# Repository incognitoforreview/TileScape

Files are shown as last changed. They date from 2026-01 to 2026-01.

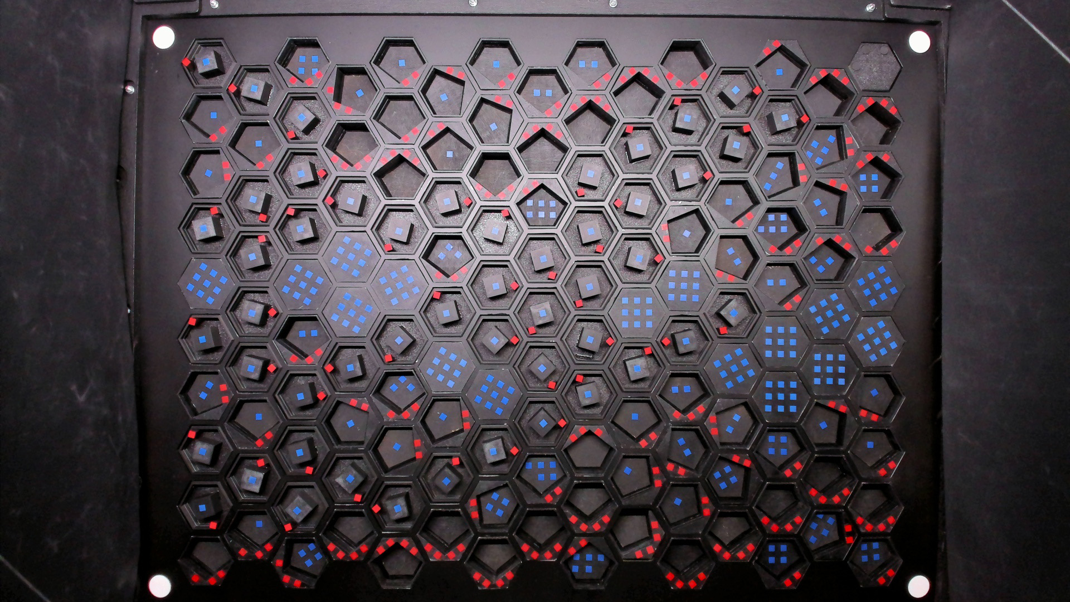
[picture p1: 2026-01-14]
input_files/DMG_table1.jpg

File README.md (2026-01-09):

# TileScape
A repository for the tangible interaction-based TileScape set-up developed for tabletop games, including (1) design files to create the tabletop set-up; (2) template files to create tangible game pieces; and (3) the tracking algorithm to capture the game pieces placed on the tabletop.

## Build & Test
The design_files folder offers shape files, drawings and instructions for building TileScape or create an adapted version. It is set-up with subfolders around certain parts of the set-up, with each folder containing a readme pdf.

The code in the main folder is used to track the physical game pieces on TileScape's board. It can be initiated by creating an object of the TileScape class located in the tilescape.py file. It can be run in a test mode, which takes images from the TileScape set-up located in the input_files folder as a basis. The main call in tilescape.py currently initiates this test mode. To run it, you will need to set a local folder in line 64.

## Use & cite
All files and code are shared under the GPL-3.0 license (see license tab). By downloading and using TileScape, you agree to cite TileScape in any publication based on research in which TileScape is used or that builds on its concept. 

When citing TileScape, the following APA style reference can be used:

[anonimized for peer review] (2026). TileScape: A Stackable Tile Gaming Tabletop for Shaping Discrete 3D Terrains with Augmented Physics Simulations. [Manuscript submitted for publication]. [removed for peer review].

## Contact & Support
If you have questions, want some support or simply get in contact about this work, please contact [removed for peer review] via [removed for peer review].

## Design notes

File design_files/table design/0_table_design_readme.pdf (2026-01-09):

In this folder, subfolders are located with each containing specic information to produce the TIlescape or a similar set-up.

The gure on the right shows the full set-up as presented in the paper [citation anonimized for peer review]. Each folder focuses on a subpart of the set-up with its own les and a dedicated readme for instructions.

Any changes to the set-up (e.g. dierent grid size or use of dierent hardware) may need adaption of the les in this repository.

Please reach out for any guidance where needed or if any instructions are unclear or seem incomplete.

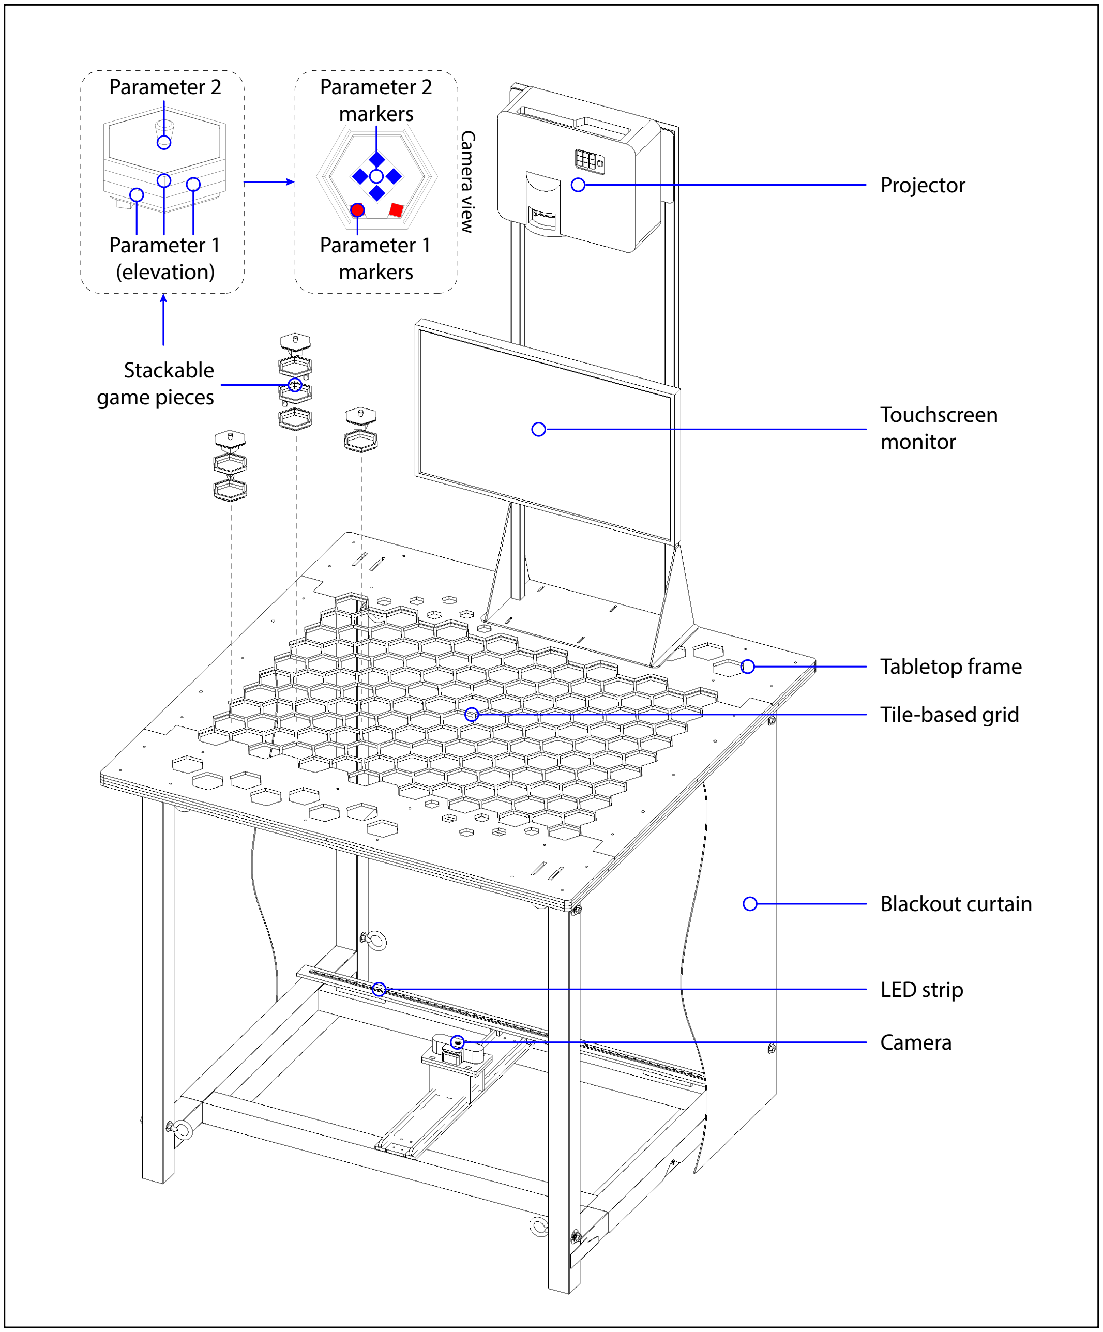
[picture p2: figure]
Projector; Parameter 2; markers; Parameter 1 (elevation); Parameter 1 markers; Camera view; Stackable; game pieces; Touchscreen; monitor; Tabletop frame; Tile-based grid; Blackout curtain; LED strip; Camera

Figure source: [Anonimized for peer review] (2026). TileScape: A Stackable Tile Gaming Tabletop for Shaping Discrete 3D Terrains with Augmented Physics Simulations [Manuscript submitted for publication]. [Anonimized for peer review].

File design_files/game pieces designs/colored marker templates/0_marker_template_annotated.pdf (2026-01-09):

The colored markers are squares, added as stickers in the color used for a specic parameter. We used a sticker printer capable of cutting the squares from a uniform color sticker, using transfer tape to preserve equal spacing betweek markers. The blue boxes indicate patterns for number of markers from 1 to 9.

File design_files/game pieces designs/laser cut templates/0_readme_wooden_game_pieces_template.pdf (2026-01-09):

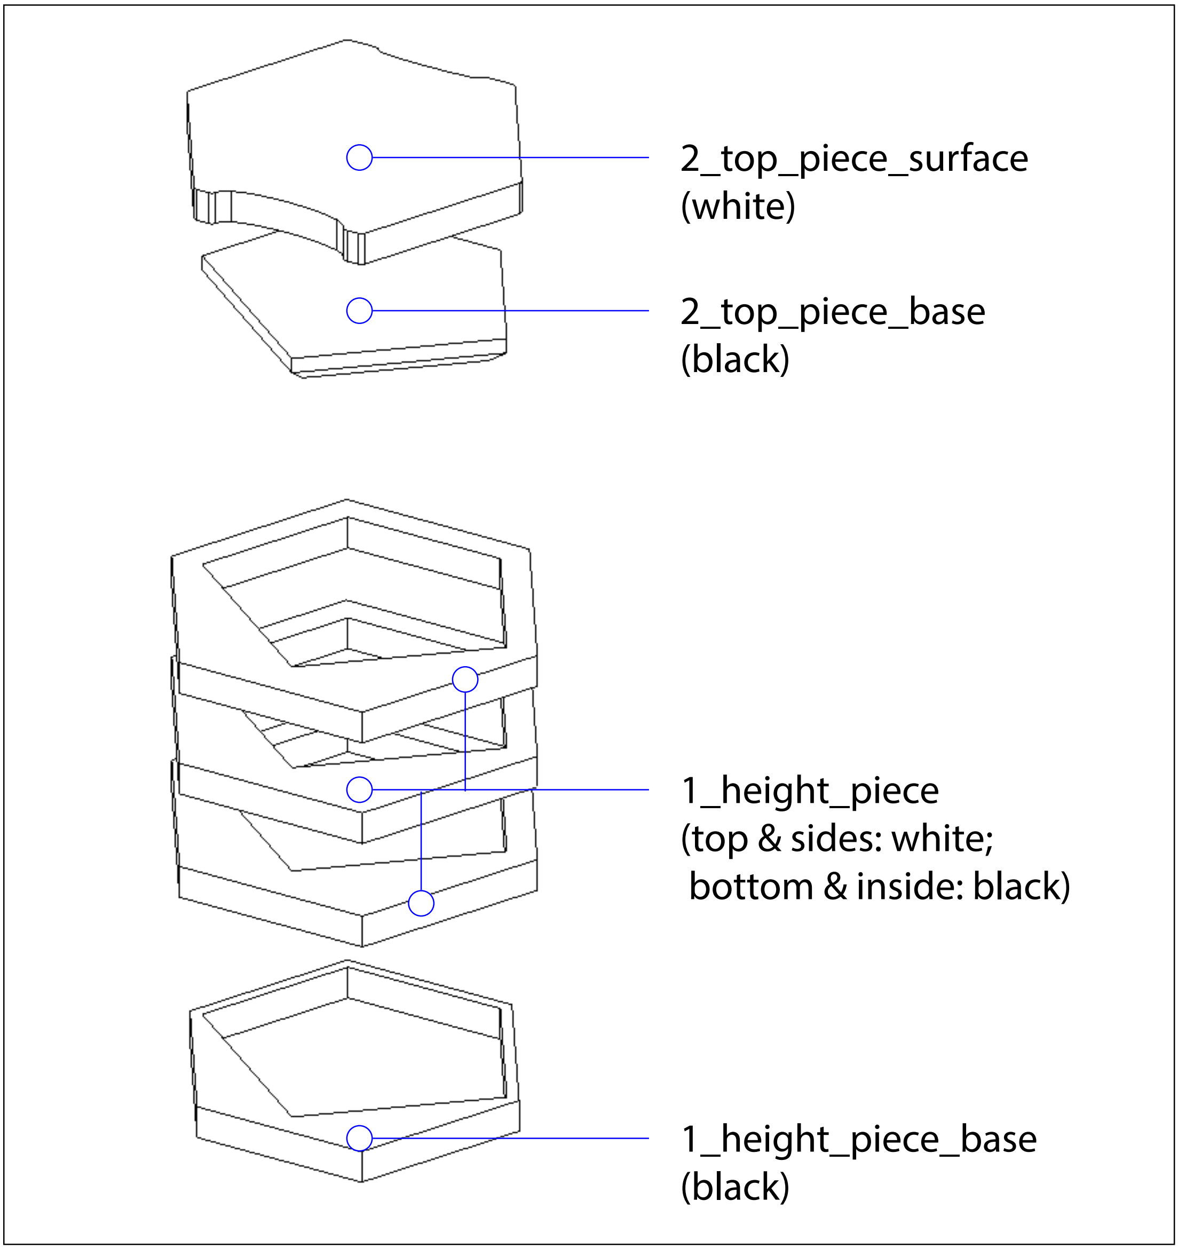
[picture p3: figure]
2_top_piece_surface (white); 2_top_piece_base (black); 1_height_piece (top & sides: white; bottom & inside: black); 1_height_piece_base (black)

The les in this folder oer templates for lasercutting layered pieces from wood for use on Tilescape. Each template is oered as a .dxf and .ai (Adobe Illustrator). All parts can be laser cut from standard wood sheets. We recommend 6 mm thick sheets.

The gure on the right shows the template les and how they are stacked on Tilescape. Dierent number of 1_height_piece can be glued together for dierent levels of elevation. We recommend to use a mold for glueing from the inner shapes cut out for creating the pieces and sanding the resulting shape after glueing. Afterwards, the pieces require painting, with recommended colors shown on the gure per shape. We recommend a matte paint nish. After painting, glue the les for 1 together and do the same for 2, which can then be stacked ontop of each other.

The 2_top_piece_surface can be modied to include 2D icons or 3D shapes to represent meanings. 3D shapes can be freely designed and glued ontop. We recommend creating 2D icons by including cut-out shapes in the lasercutting, which then shows the surface of the black 2_top_piece_base underneath to create a contrast. Using stickers is an alternative, but may add reections to the top-down projections.

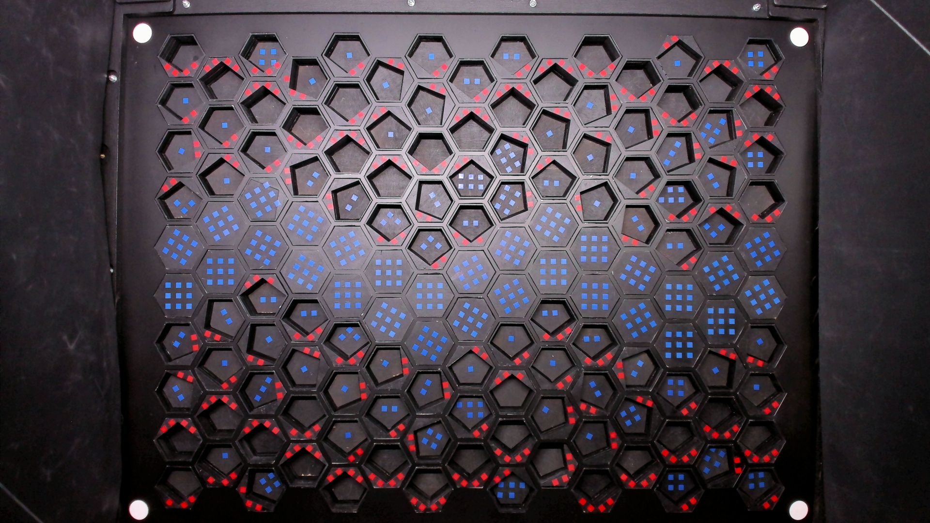
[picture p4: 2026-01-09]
input_files/VRG_table1.jpg

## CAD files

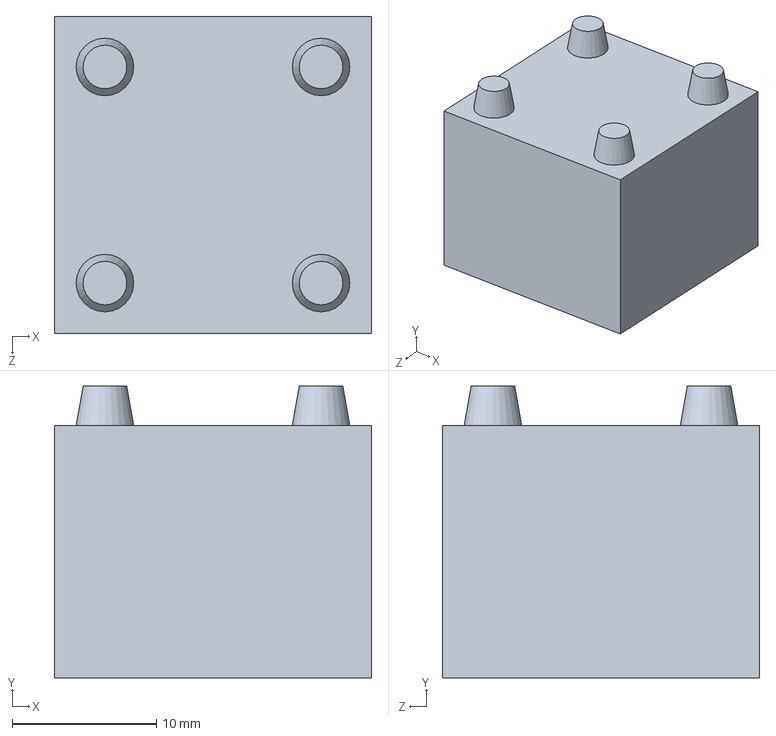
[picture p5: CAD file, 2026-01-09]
design_files/game pieces designs/3D print templates/3_top_piece_extension_template.SLDPRT
22.0 x 20.2 x 22.0 mm

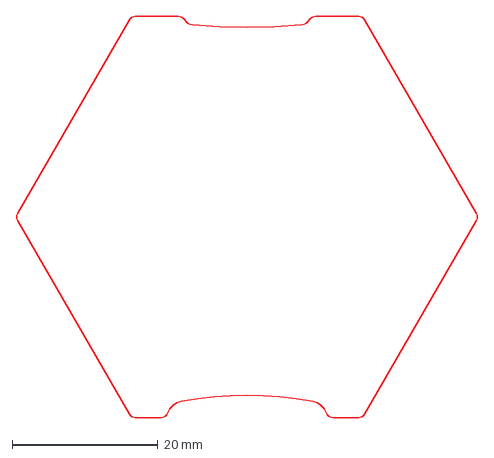
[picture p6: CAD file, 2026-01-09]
design_files/game pieces designs/laser cut templates/2_top_piece_surface.dxf
63.3 x 55.0 mm

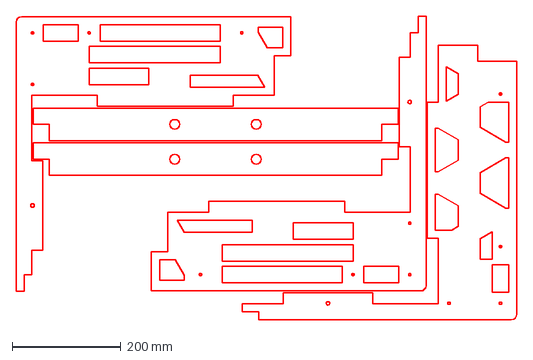
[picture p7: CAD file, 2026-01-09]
design_files/table design/table surface/tabletop_frame_1.dxf
921.0 x 557.7 mm

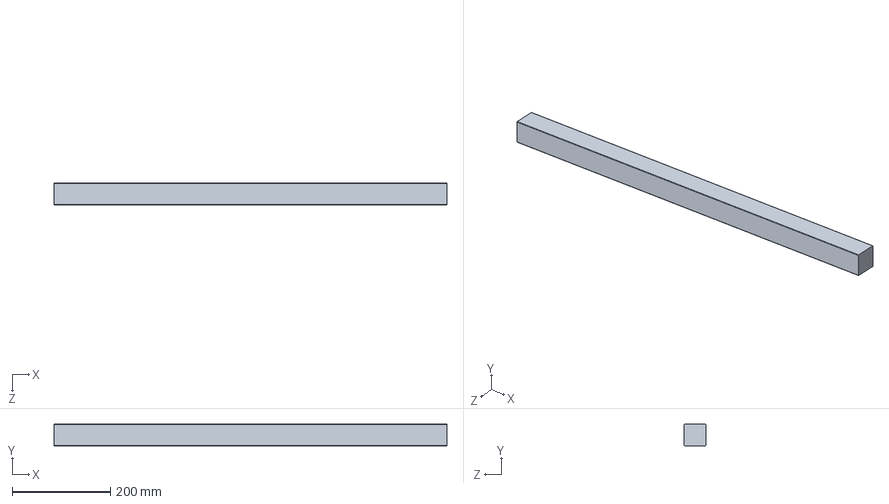
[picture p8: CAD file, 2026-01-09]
design_files/table design/table underside/legs & frame/3_cross_beam_x2.SLDPRT
800.0 x 44.0 x 44.0 mm

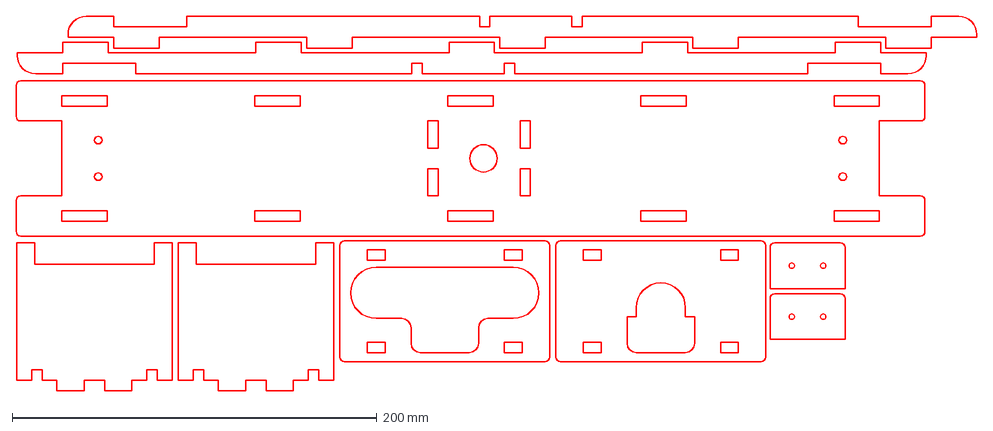
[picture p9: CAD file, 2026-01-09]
design_files/table design/table underside/webcam mount/webcam_mount_laser_cut_shapes.dxf
526.4 x 205.2 mm

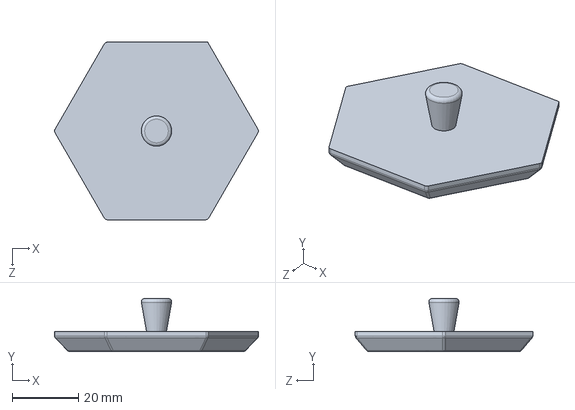
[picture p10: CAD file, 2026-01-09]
design_files/game pieces designs/3D print templates/3_top_piece_template.SLDPRT
61.5 x 16.0 x 53.5 mm

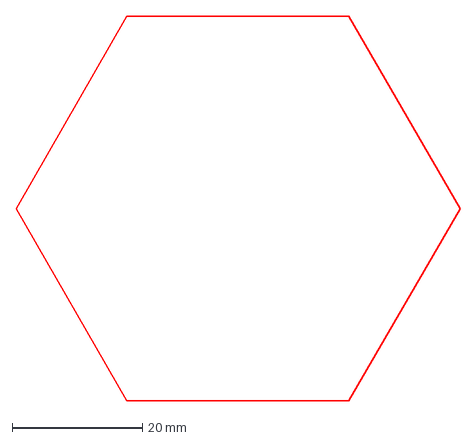
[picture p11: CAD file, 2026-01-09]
design_files/game pieces designs/laser cut templates/3_no_elevation_surface.dxf
68.1 x 59.0 mm

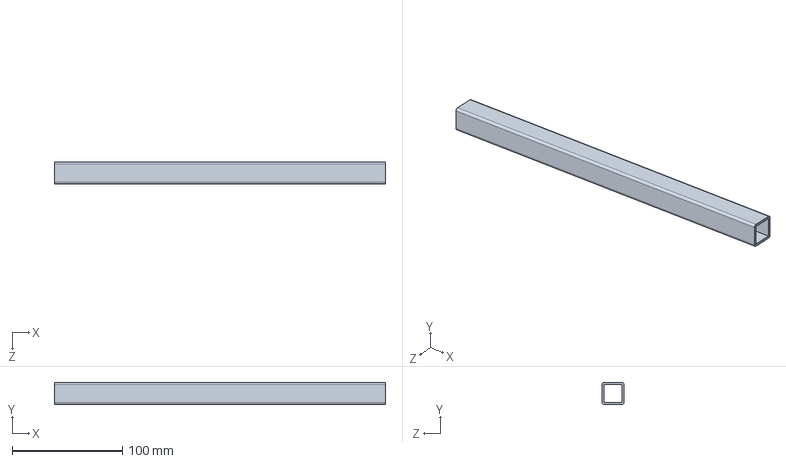
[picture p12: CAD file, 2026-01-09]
design_files/table design/projector and touchscreen frame/3_cross_beam_bottom.sldprt
300.2 x 20.0 x 20.0 mm

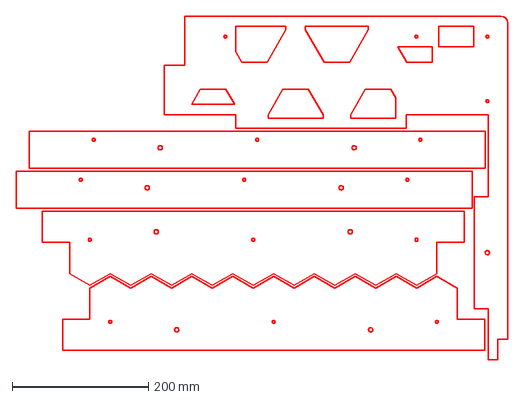
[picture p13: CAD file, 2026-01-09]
design_files/table design/table surface/tabletop_frame_2.dxf
722.5 x 505.0 mm

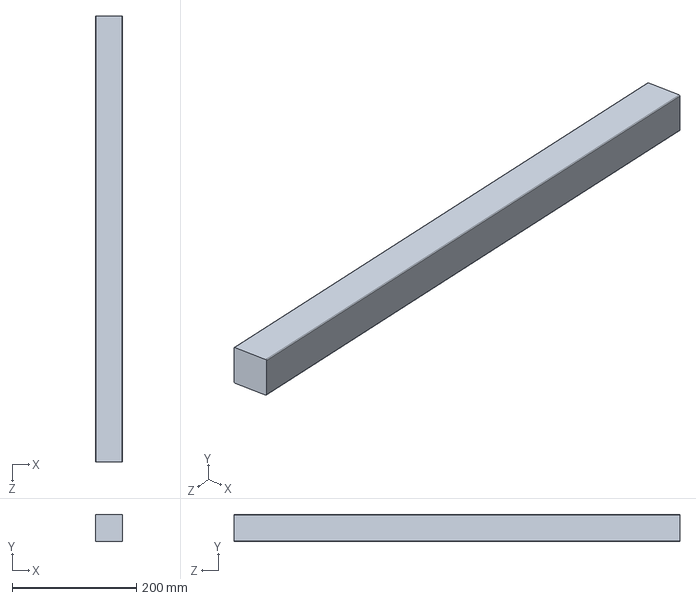
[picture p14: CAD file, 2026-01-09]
design_files/table design/table underside/legs & frame/2_side_beam_x2.SLDPRT
44.0 x 44.0 x 719.0 mm

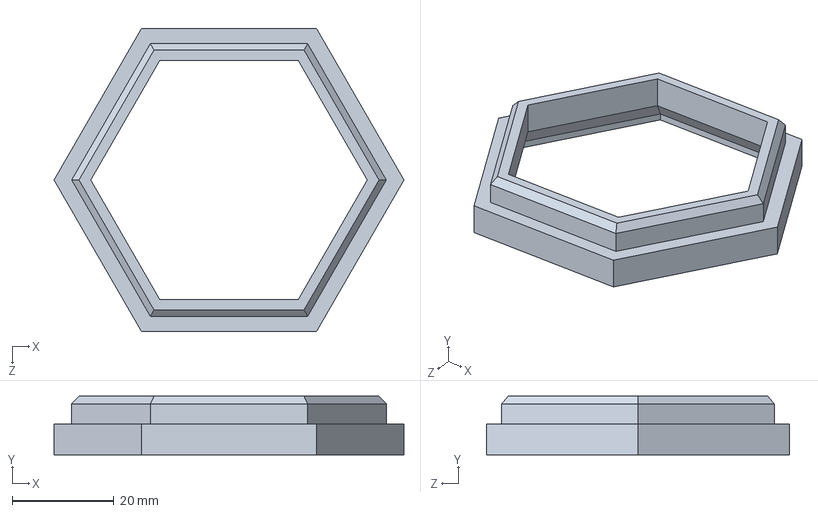
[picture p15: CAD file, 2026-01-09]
design_files/game pieces designs/3D print templates/1_base_elevation_template.SLDPRT
68.7 x 11.5 x 59.5 mm

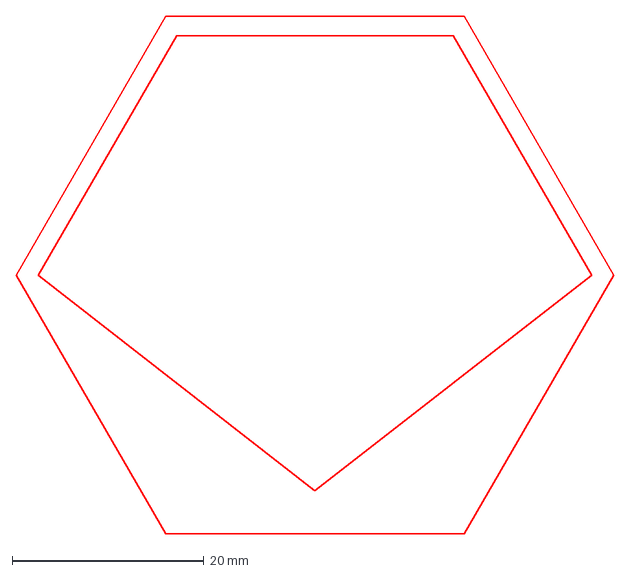
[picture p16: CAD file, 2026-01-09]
design_files/game pieces designs/laser cut templates/1_height_piece_base.dxf
62.4 x 54.0 mm

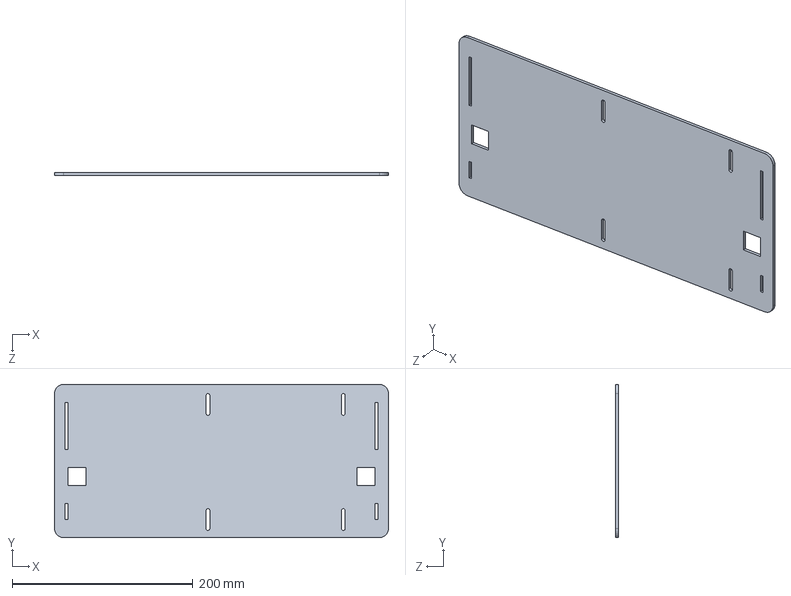
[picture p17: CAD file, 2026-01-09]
design_files/table design/projector and touchscreen frame/0_base_plate_3mm.sldprt
370.0 x 169.8 x 3.00 mm

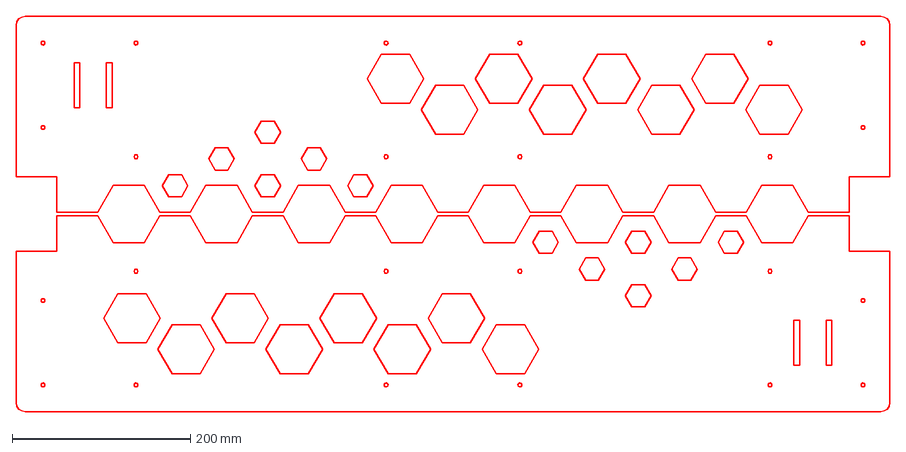
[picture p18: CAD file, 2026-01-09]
design_files/table design/table surface/tabletop_frame_4.dxf
980.0 x 443.5 mm

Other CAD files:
design_files/table design/projector and touchscreen frame/4_screen_assembly_plate_2mm.sldprt
design_files/table design/projector and touchscreen frame/6_beamer_assembly_plate_2mm.sldprt
design_files/table design/table underside/legs & frame/1_table_leg_x4.sldprt
design_files/game pieces designs/3D print templates/2_additional_elevation_template.SLDPRT
design_files/game pieces designs/3D print templates/1_base_elevation_template.STL
design_files/game pieces designs/3D print templates/2_additional_elevation_template.STL
design_files/game pieces designs/3D print templates/3_top_piece_extension_template.STL
design_files/game pieces designs/3D print templates/3_top_piece_template.STL
design_files/game pieces designs/laser cut templates/1_height_piece.dxf
design_files/game pieces designs/laser cut templates/2_top_piece_base.dxf
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

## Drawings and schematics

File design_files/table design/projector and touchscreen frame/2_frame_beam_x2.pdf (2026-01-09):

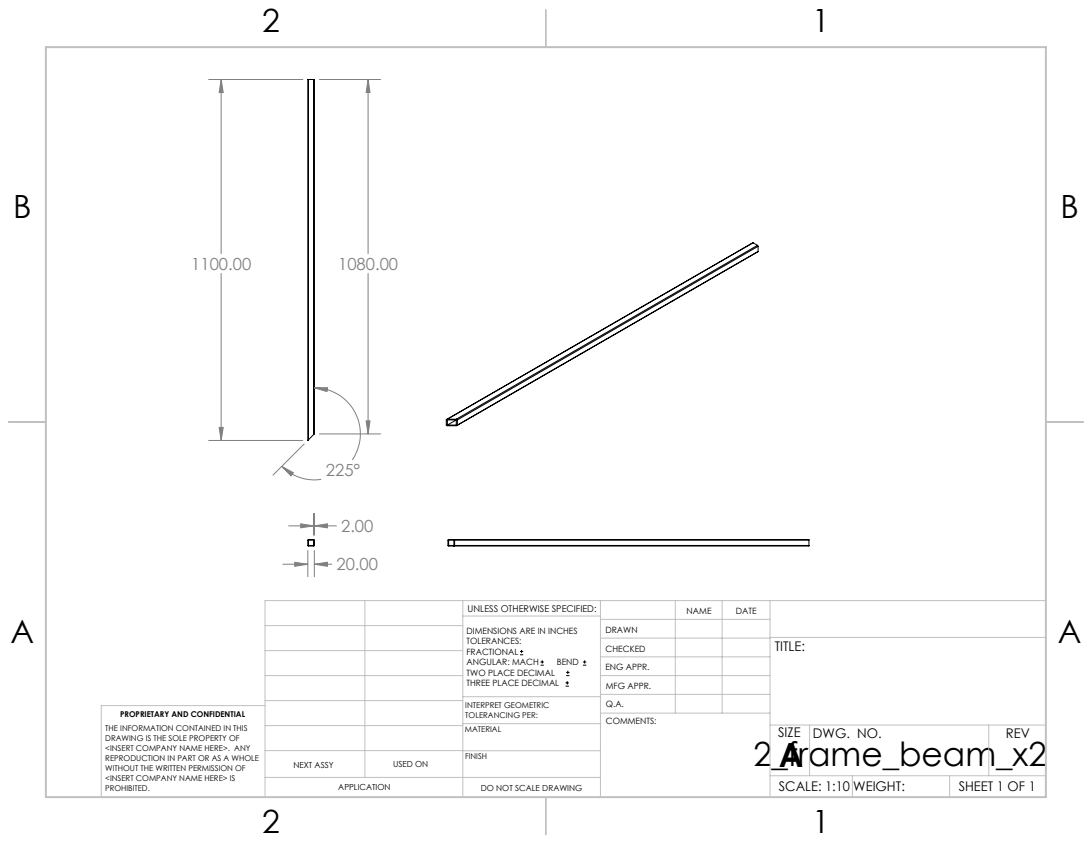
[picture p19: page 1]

UNLESS OTHERWISE SPECIFIED: | | NAME | DATE
DIMENSIONS ARE IN INCHES TOLERANCES: FRACTIONAL ANGULAR: MACH BEND TWO PLACE DECIMAL THREE PLACE DECIMAL | DRAWN

CHECKED | | | TITLE:

ENG APPR.
MFG APPR.

INTERPRET GEOMETRIC TOLERANCING PER: | Q.A.
MATERIAL | 2_frame_beam_x2 | SIZE A | DWG. NO. | REV

PROPRIETARY AND CONFIDENTIAL
THE INFORMATION CONTAINED IN THIS
DRAWING IS THE SOLE PROPERTY OF
<INSERT COMPANY NAME HERE>. ANY
REPRODUCTION IN PART OR AS A WHOLE
WITHOUT THE WRITTEN PERMISSION OF
<INSERT COMPANY NAME HERE> IS
PROHIBITED.

NEXT ASSY | USED ON | FINISH

APPLICATION | DO NOT SCALE DRAWING | | SCALE: 1:10 WEIGHT: | | SHEET 1 OF 1

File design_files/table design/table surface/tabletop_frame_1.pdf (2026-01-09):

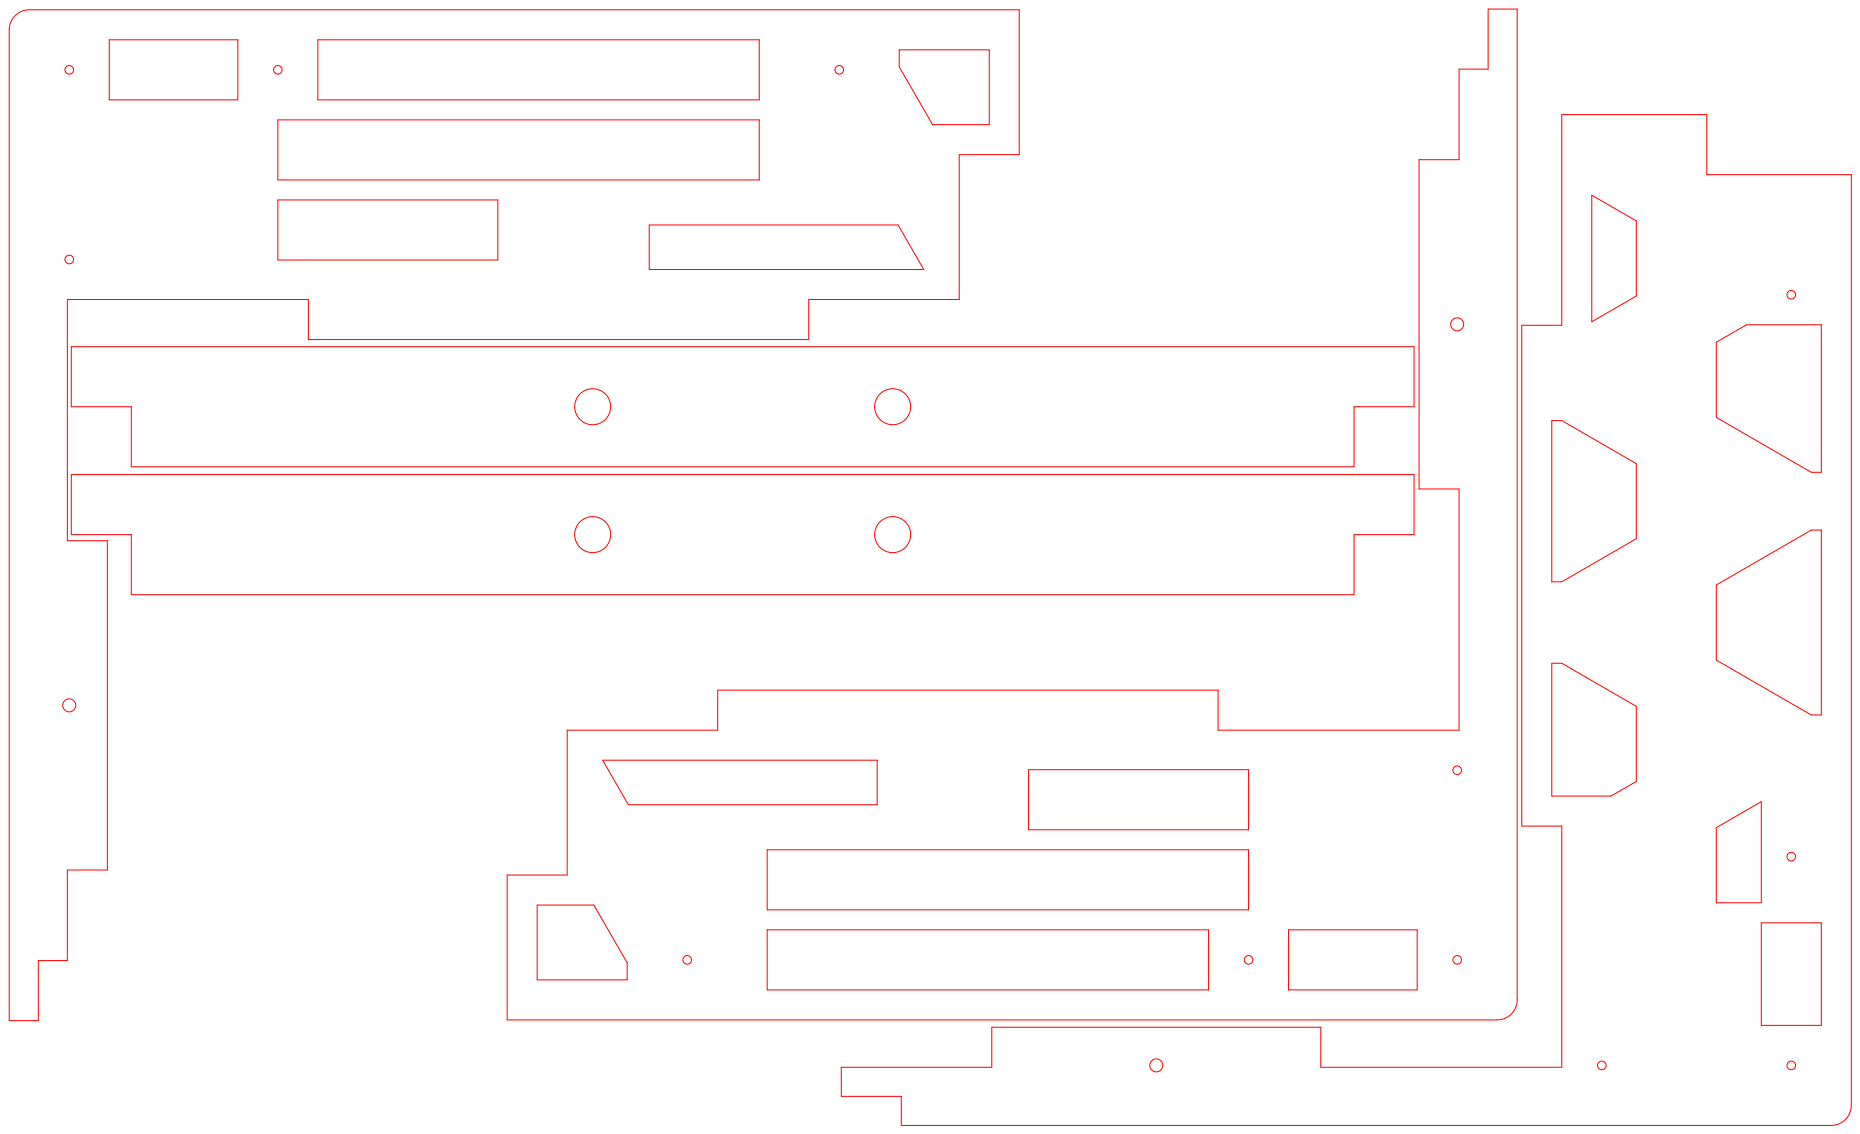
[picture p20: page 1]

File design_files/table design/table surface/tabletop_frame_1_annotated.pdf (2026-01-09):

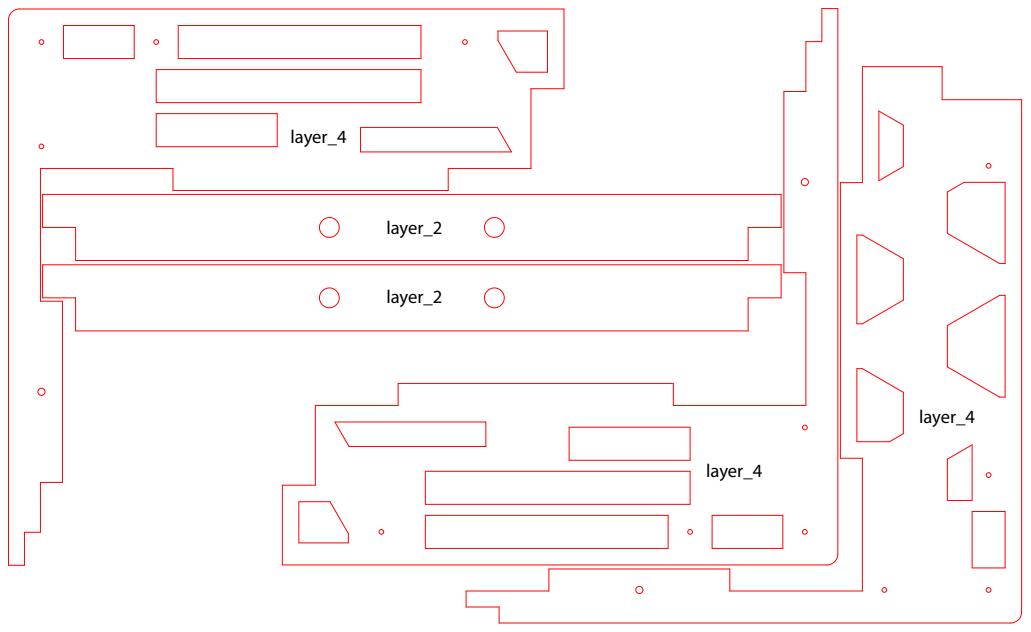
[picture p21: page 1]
layer_2; layer_4

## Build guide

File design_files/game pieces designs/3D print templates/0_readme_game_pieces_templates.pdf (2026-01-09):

The les in this folder oer templates for 3D printing pieces for use on Tilescape. Each template is oered as a .dxf and .sldprt (SolidWorks part). All parts can be printed with standard PLA lament. We recommend the use of lament with a matte nish.

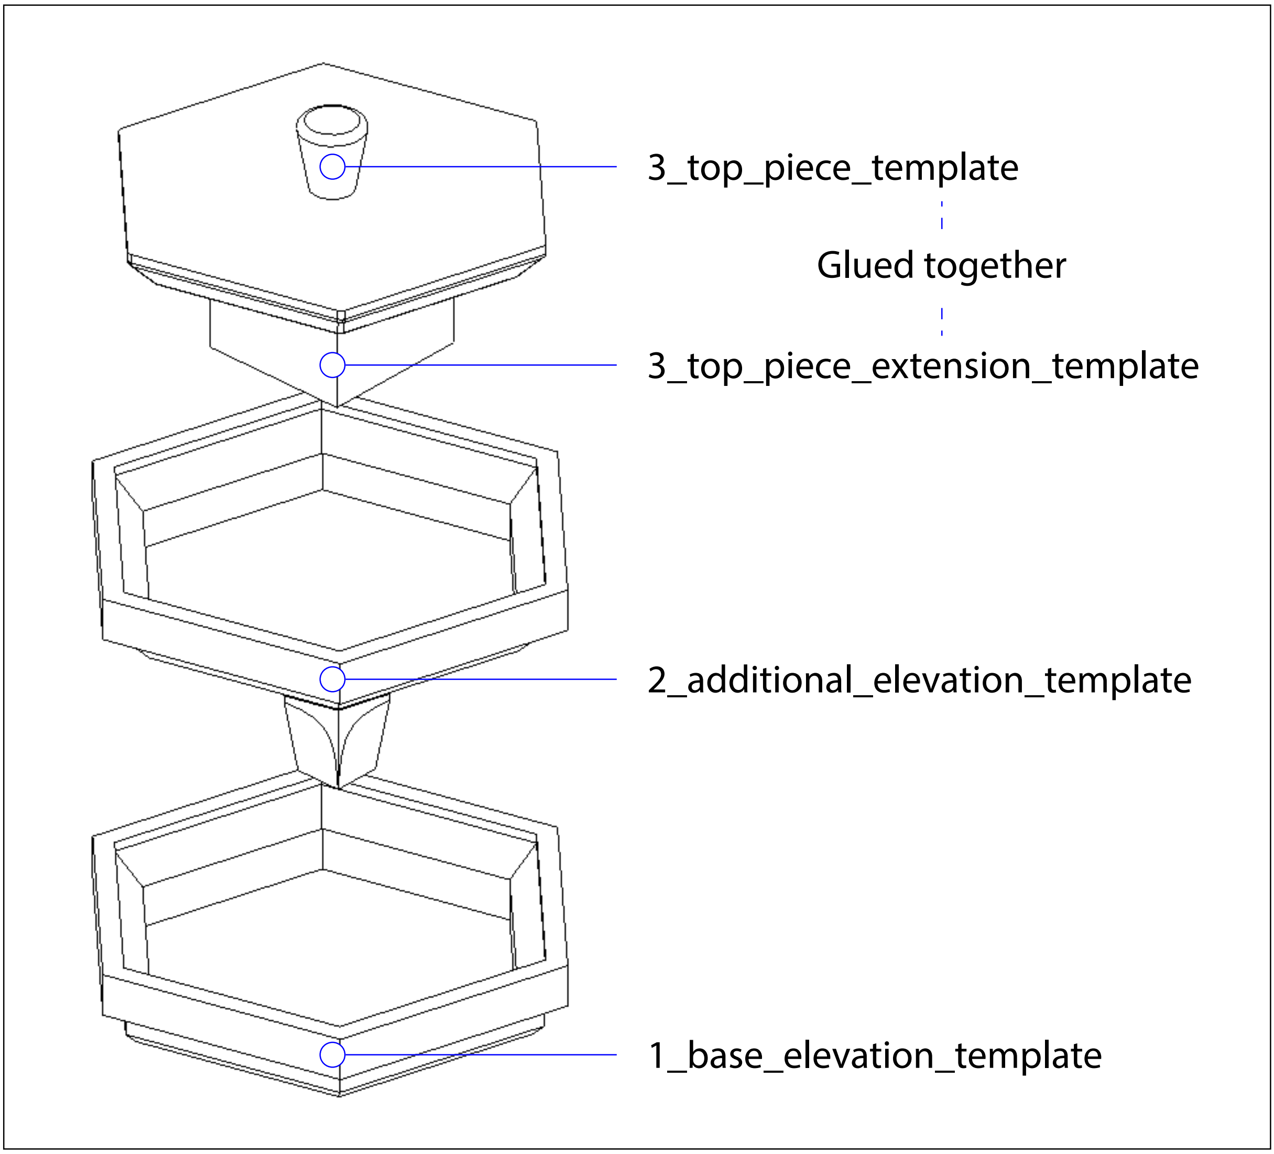
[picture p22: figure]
3_top_piece_template; 3_top_piece_extension_template; 2_additional_elevation_template; 1_base_elevation_template; Glued together

The gure on the right shows the template les and how they are stacked on Tilescape. The 3_top_piece is 3D printed in two parts for eciency purposes as it eliminates the need for printing supports. The two components self-align from their shapes and can be glued together with super glue.

3_top_piece_extension_template is printed fully in black. All other parts are printed with black lament and the bottom (from the right assembly perspective, the 1 and 2 pieces are printed upside down) and switching to white at a set layer, which can be selfdetermined as long as colors underneath do not shine through.

The 3_top_piece_template can be modied to include 2D icons or 3D shapes to represent meanings. 3D shapes can be freely designed. We recommend creating 2D icons by making cut-out shapes in the white top surface up to the black layer underneath to create a contrast. Using stickers is an alternative, but may add reections to the top-down projections.

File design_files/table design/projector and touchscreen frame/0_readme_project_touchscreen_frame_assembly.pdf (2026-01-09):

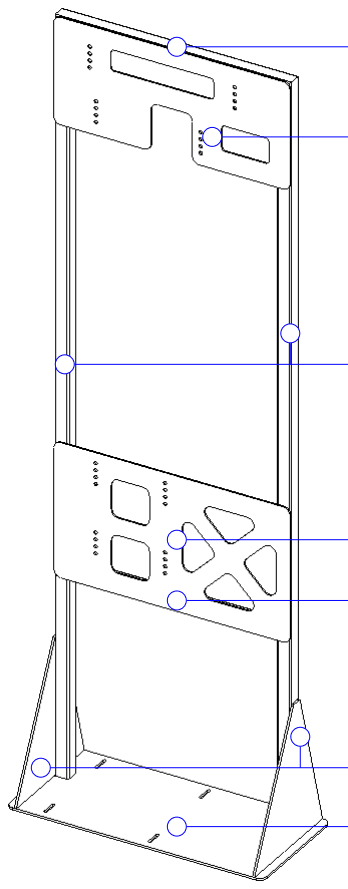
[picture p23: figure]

0_base_plate_3mm

3_cross_beam_bottom
(behind screen assembly plate)

4_screen_assembly_plate_2mm

6_beamer_assembly_plate_2mm

5_cross_beam_top
(behind beamer assembly plate)

Assembly of the frame to which the projector and the touchscreen are mounted.

All components are metal, welded together

1_rib_3mm_x2

2_frame_beam_x2

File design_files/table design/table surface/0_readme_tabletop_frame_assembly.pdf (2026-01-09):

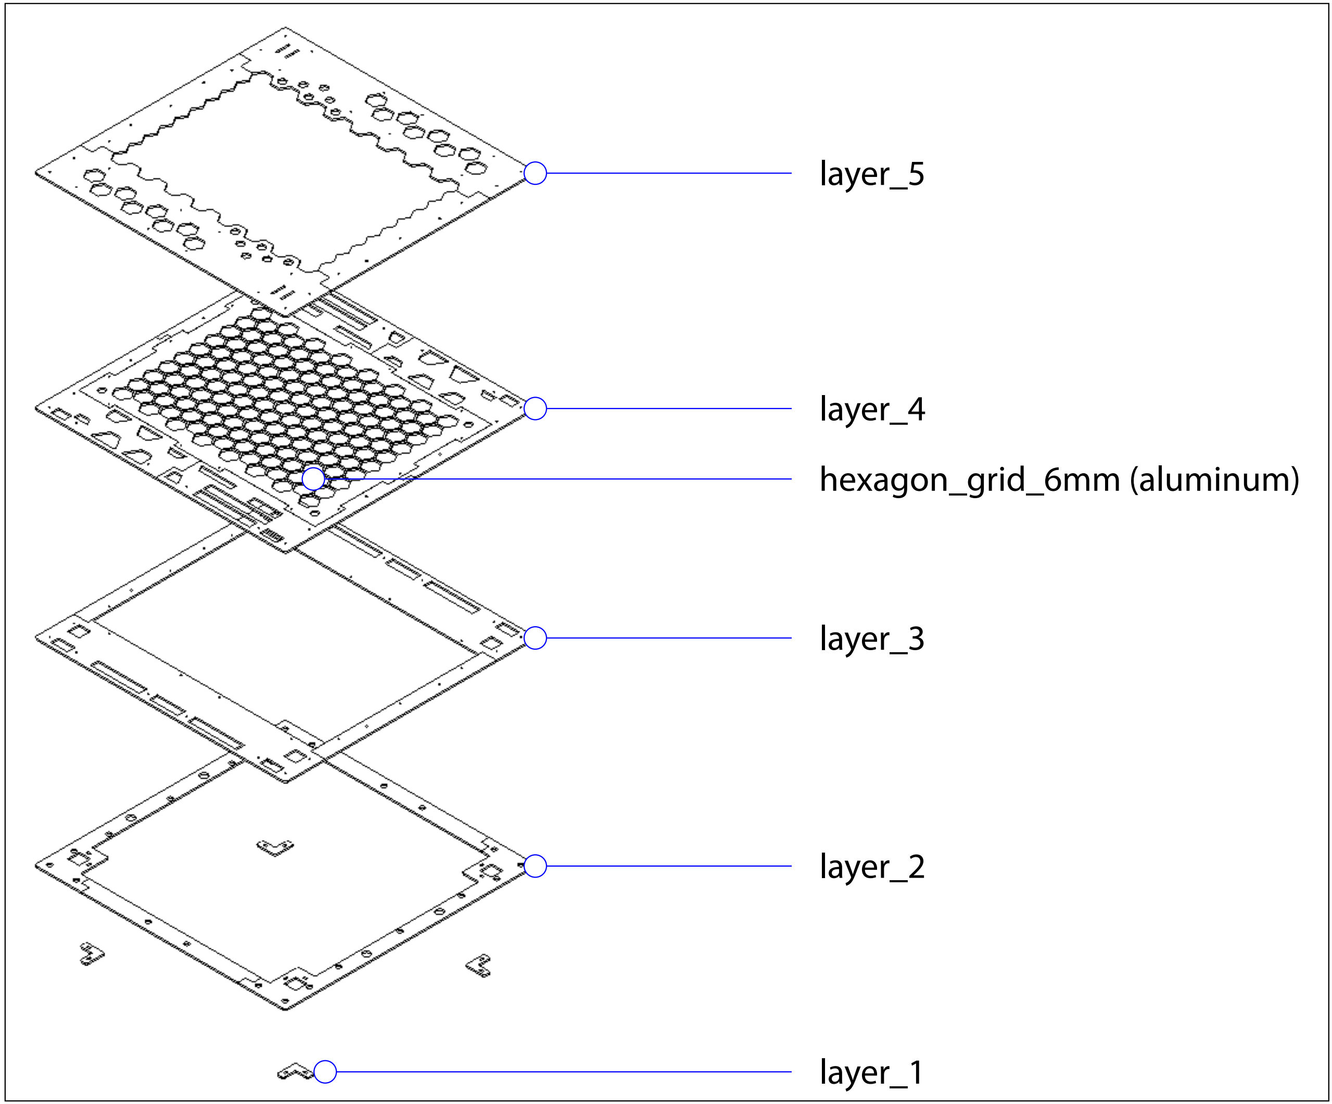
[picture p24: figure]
layer_5; layer_4; hexagon_grid_6mm (aluminum); layer_3; layer_2; layer_1

The les in this folder can be used to create the tabletop frame of Tilescape. It is build up in layers of 6mm wood, with shapes created through laser cutting. Exception to this is the hexagon_grid_6mm shape, which is laser cut from 6mm aluminum.

For construction, the gure on the right shows the assembly as layers. In the folder, ve les are available that include all shapes to lasercut from wood in three formats (.dxf, .ai and .pdf). Each also has a dedicated pdf with annotation of which layer the shape belongs to. A minimum bed level of 1000x600 mm is required. The gure on the right can be used to further
build the frame.

After all shapes are cut, layer_1, layer_2, layer_3 and layer_4 are glued together. Circles are included in the lasercut shapes to help alignment. Afterwards, paint the bottom side of the glued frame black and the sides white. Paint the hexagon_grid_6mm black. Paint layer_5 completely white. We recommend pre-drilling the holes for nuts before painting these pieces (see next paragraph) to ensure a at topside. We recommend a matte paint nish.

After painting, place the hexagon_grid_6mm in the glued frame. Place the shapes from layer_5 ontop. Use 4mm nuts and bolts to further assemble the complete frame.

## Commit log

2026-01-09 Add design files via upload
    [0_base_plate_3mm.DXF, 0_base_plate_3mm.sldprt, 1_base_elevation_template.SLDPRT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]
2026-01-14 Updated test code to include both games
    test files now include both games and code can be switched easily to run test files of the other game.
    additionally added/updated comments in both uploaded files.
